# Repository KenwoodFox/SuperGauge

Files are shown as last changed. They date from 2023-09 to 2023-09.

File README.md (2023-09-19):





# SuperGauge

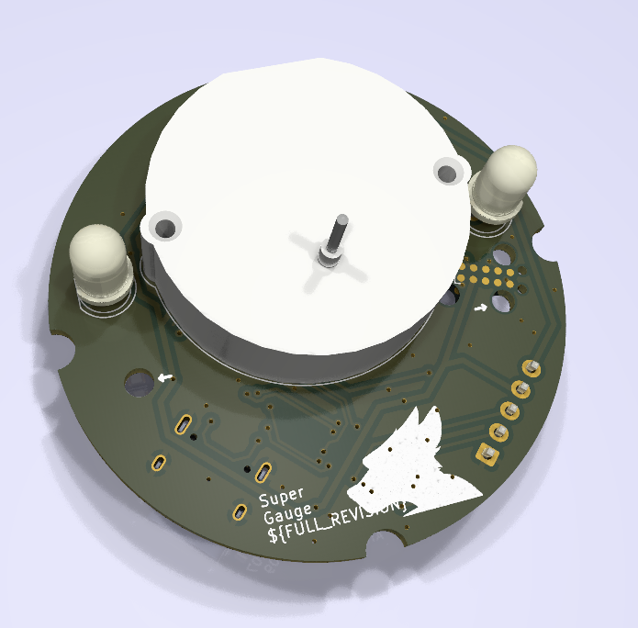
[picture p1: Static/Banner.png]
Banner


This repo contains all the firmware and hardware for the SuperGauge.

If you're looking for the latest docs/builds, see our [Releases Page](https://github.com/KenwoodFox/SuperGauge/releases).

# Getting Started

First, clone this repo (and optionally checkout a branch)

```shell
git clone https://github.com/KenwoodFox/SuperGauge.git
cd SuperGauge
```

# Init Submodules

Some libraries and resources are included as submodules, run the following
command to initialize them before opening the main sch

(If you get a missing library error, make sure to do this)

```shell
git submodule update --init --recursive
```

## Project Layout

If you want to use this project template for yourself, you can find it [here!](https://github.com/KenwoodFox/Project-Template)

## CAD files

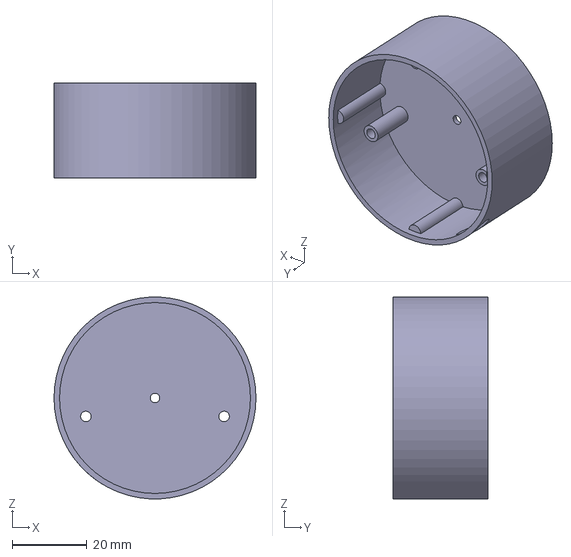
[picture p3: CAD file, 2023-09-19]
CAD/Face.FCStd
54.0 x 25.4 x 53.9 mm

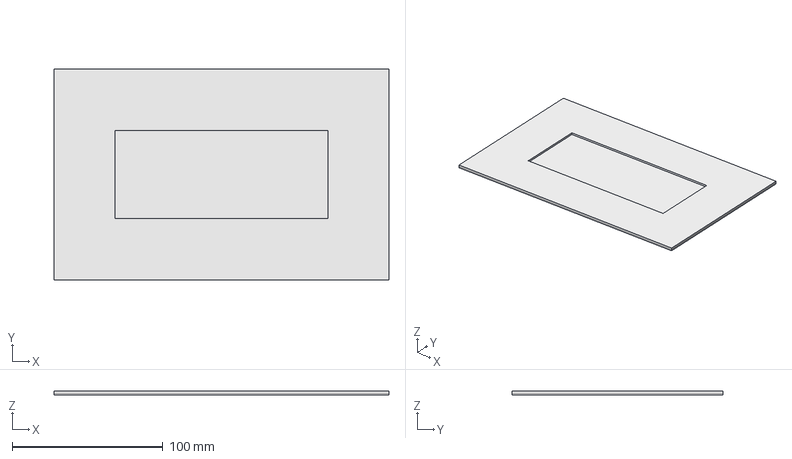
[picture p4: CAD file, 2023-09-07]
Hardware/SuperGauge/Stencils/SolderMaskStencil.FCStd
222.2 x 139.7 x 2.60 mm

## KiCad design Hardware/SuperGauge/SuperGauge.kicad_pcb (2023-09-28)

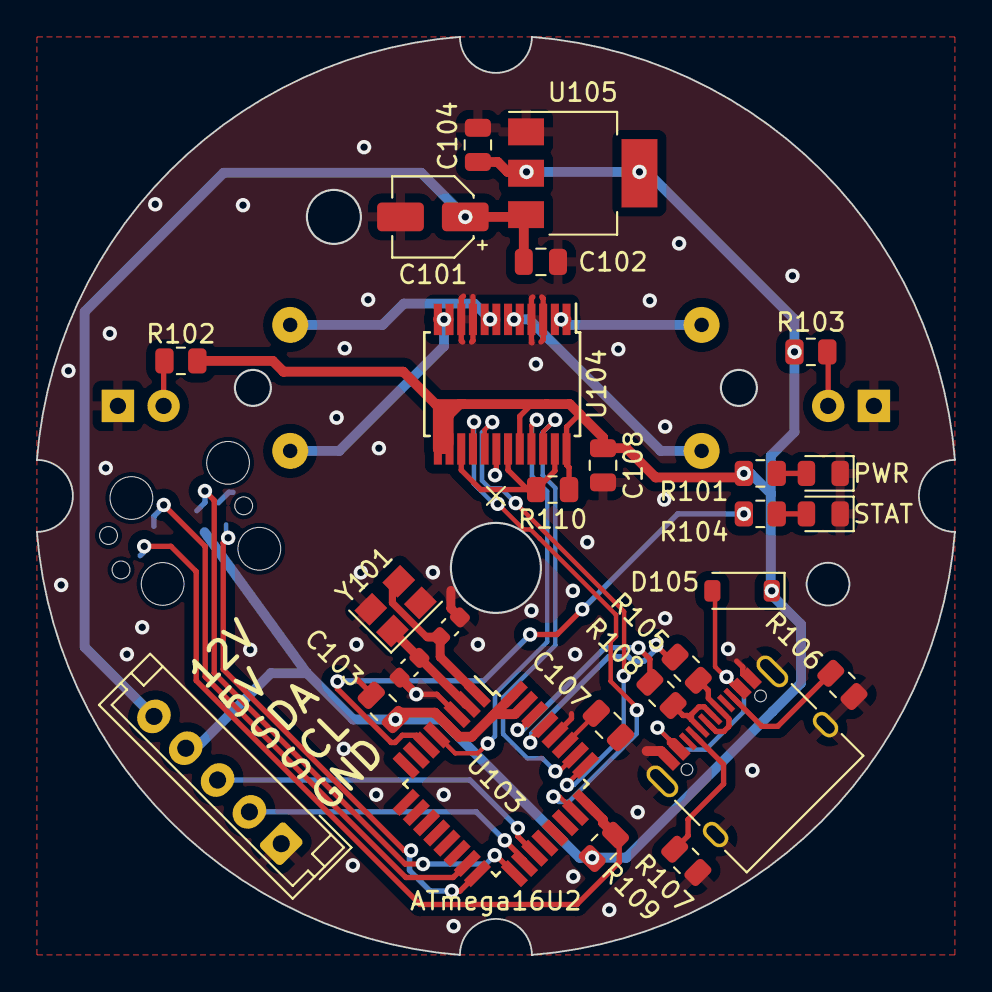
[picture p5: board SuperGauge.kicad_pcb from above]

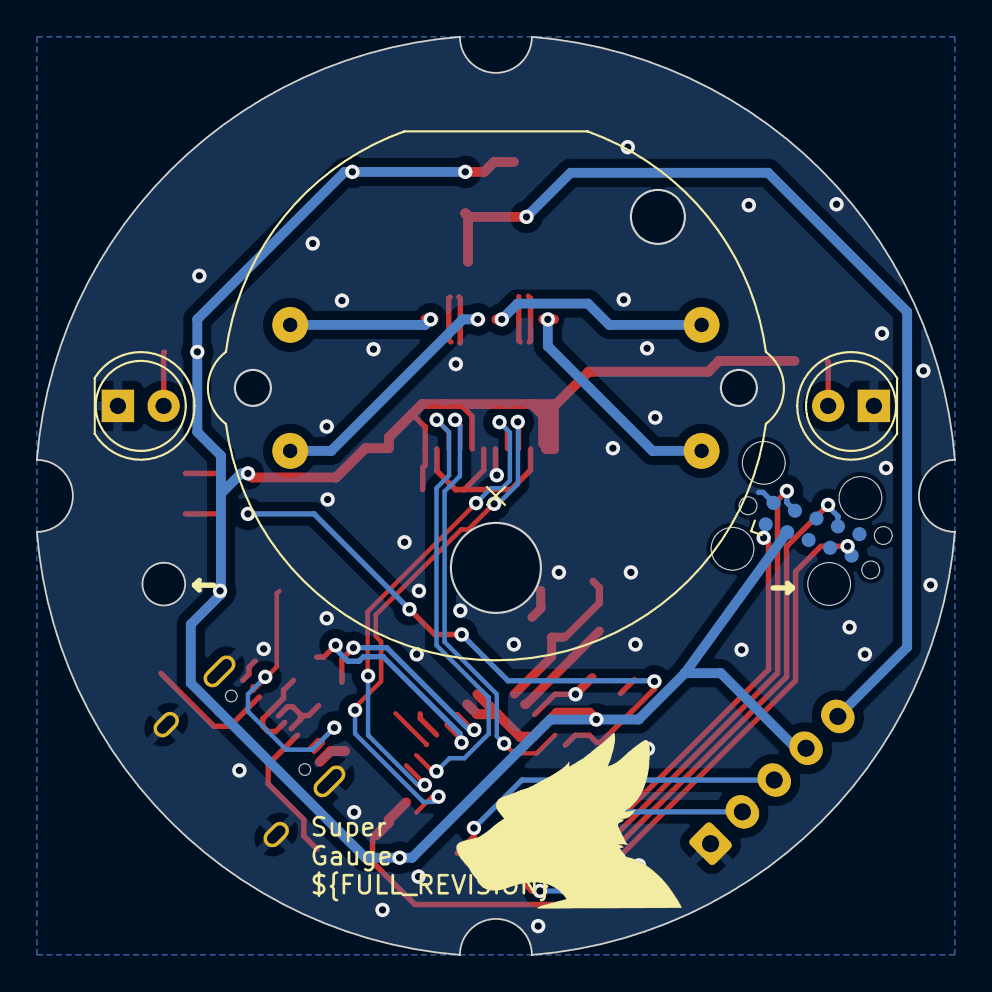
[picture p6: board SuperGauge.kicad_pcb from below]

Board: 2 copper layers, 51.0 x 51.0 mm, 31 parts (4 on the bottom side), 33 nets.

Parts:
C101: 10uf; CP_Elec_4x3
C102, C103: 100nF; C_0805_2012Metric
C104: 1uF; C_0805_2012Metric
C105, C106: 22pf; C_0603_1608Metric
C107, C108: 1u; C_0805_2012Metric
D101: PWR; LED_0805_2012Metric
D102, D103: BACKLIGHTING; LED_D5.0mm_Clear
D104: STAT; LED_0805_2012Metric
D105: MBR0520LT; D_SOD-123
J101: USBC; USB_C_Receptacle_XKB_U262-16XN-4BVC11
J102: MainConn; JST_EH_B5B-EH-A_1x05_P2.50mm_Vertical
J103: Tag Connect; Tag-Connect_TC2050-IDC-FP_2x05_P1.27mm_Vertical
R101, R102, R103, R104: 1K; R_0805_2012Metric
R105, R108: 22R; R_0805_2012Metric
R106, R107: 5K1; R_0805_2012Metric
R109, R110: 10k; R_0805_2012Metric
U101: X27-168
U103: ATmega16U2; TQFP-32_7x7mm_P0.8mm
U104: TB6612FNG; SSOP-24_5.3x8.2mm_P0.65mm
U105: LM1117MP-5.0; SOT-223-3_TabPin2
Y101: Crystal_GND24; Crystal_SMD_3225-4Pin_3.2x2.5mm

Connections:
+5V: C103.1, C104.1, C108.1, D105.1 (K), J102.4, J103.2, R101.1, R102.1, R103.1, R109.2, R110.1, U103.4 (VCC), U103.31 (UVCC), U103.32 (AVCC), U104.13 (VM2), U104.14 (VM3), U104.20 (VCC), U104.24 (VM1), U105.2 (VO)
+12V: C101.1, C102.1, J102.5, U105.3 (VI)
/AIN1: U103.5 (PC2), U104.21 (AIN1)
/AIN2: U103.26 (PC4), U104.22 (AIN2)
/BIN1: U103.25 (PC5), U104.17 (BIN1)
/BIN2: U103.23 (PC6), U104.16 (BIN2)
/ICSP_MISO: J103.9, U103.17 (PB3)
/ICSP_MOSI: J103.1, U103.16 (PB2)
/ICSP_RST: J103.5, R109.1, U103.24 (PC1/~RESET)
/ICSP_SCK: J103.7, U103.15 (PB1)
/SCL: J102.2, U103.18 (PB4)
/SDA: J102.3, U103.19 (PB5)
/USB+: J101.A6 (D+), J101.B6 (D+), R105.1
/USB-: J101.A7 (D-), J101.B7 (D-), R108.1
/XTAL1: C106.1, U103.1 (XTAL1), Y101.3
/XTAL2: C105.1, U103.2 (PC0/XTAL2), Y101.1
GND: C101.2, C102.2, C103.2, C104.2, C105.2, C106.2, C107.2, C108.2, D101.1 (K), D102.1 (K), D103.1 (K), D104.1 (K), J101.A1 (GND), J101.A12 (GND), J101.B1 (GND), J101.B12 (GND), J101.S1 (SHIELD), J102.1, J103.10, R106.1, R107.1, U103.3 (GND), U103.28 (UGND), U104.3 (PGND1), U104.4 (PGND1), U104.9 (PGND2), U104.10 (PGND2), U104.18 (GND), U105.1 (GND), Y101.2, Y101.4
unnamed: D101.2 (A), R101.2
unnamed: D102.2 (A), R102.2
unnamed: D103.2 (A), R103.2
unnamed: D104.2 (A), R104.2
unnamed: D105.2 (A), J101.A4 (VBUS), J101.A9 (VBUS), J101.B4 (VBUS), J101.B9 (VBUS)
unnamed: J101.A5 (CC1), R107.2
unnamed: J101.B5 (CC2), R106.2
unnamed: U101.1, U104.1 (AO1), U104.2 (AO1)
unnamed: U101.2, U104.5 (AO2), U104.6 (AO2)
unnamed: U101.3, U104.11 (BO1), U104.12 (BO1)
unnamed: U101.4, U104.7 (BO2), U104.8 (BO2)
unnamed: R105.2, U103.29 (D+)
unnamed: R108.2, U103.30 (D-)
unnamed: R104.1, U103.6 (PD0)
unnamed: C107.1, U103.27 (UCAP)
unnamed: R110.2, U104.15 (PWMB), U104.19 (STBY), U104.23 (PWMA)

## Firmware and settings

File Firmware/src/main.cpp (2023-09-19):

/**
 * @file main.cpp
 * @author Joe
 * @brief Source code for SuperGauge
 */

// Libs
#include <Arduino.h>

// Headers
#include "boardPins.h"

void setup()
{
    // Pins
    pinMode(STAT_LED, OUTPUT);
}

void loop()
{
    // Flash LED
    digitalWrite(STAT_LED, HIGH);
    delay(1000);
    digitalWrite(STAT_LED, LOW);
    delay(1000);
}

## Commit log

2023-09-07 Import from cookiecutter https://github.com/KenwoodFox/Project-Template
    [Cube.FCStd, SolderMaskStencil.FCStd, SuperGauge.kicad_pcb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]
2023-09-07 Add upstream lib and new x27 motor
2023-09-07 Bump upstream again
    [SuperGauge.kicad_pcb, SuperGauge.kicad_sch]
2023-09-07 Added in MCU
    [SuperGauge.kicad_pcb, SuperGauge.kicad_sch]
2023-09-08 More stuff
    [SuperGauge.kicad_pcb, SuperGauge.kicad_sch]
2023-09-11 More PCB stuff
    [SuperGauge.kicad_pcb, SuperGauge.kicad_sch]
2023-09-13 Bump design slightly
    [SuperGauge.kicad_sch]
2023-09-13 Add motor driver
    [SuperGauge.kicad_pcb, SuperGauge.kicad_sch]
2023-09-14 Connect all
    [SuperGauge.kicad_pcb, SuperGauge.kicad_sch]
2023-09-14 Fix DRC
    [SuperGauge.kicad_pcb, SuperGauge.kicad_sch]
2023-09-15 RC time
    [SuperGauge.kicad_pcb, SuperGauge.kicad_sch]
2023-09-15 Add stencil marks
    [SuperGauge.kicad_pcb]
2023-09-19 Fix Images (#2)
    [Cube.FCStd, Face.FCStd, SuperGauge.kicad_pcb]
2023-09-28 Move mounting hole slightly
    [SuperGauge.kicad_pcb]
